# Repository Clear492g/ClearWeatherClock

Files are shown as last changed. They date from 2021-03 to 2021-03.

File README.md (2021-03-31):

# [ClearWeatherClock]拟辉光管气象钟开源文档

## 效果图

效果图

## 简述

该项目基于立创开源拟辉光钟项目和零知实验室开源ESP8266气象站项目。

只作为Demo版本发布 更多特效、功能欢迎各位有能力的朋友继续二次开发

- 核心主控为NodeMCU/ESP8266开发板 底座体积足够就没有额外画PCB（1688的NodeMCU七八块钱）
- WIFI联网 EEPROM断电保存 串口通讯
- 驱动120颗WS2812灯珠实现亚克力数字时钟展示 亮度可调 颜色可独立更改 断电记忆
- 加入旋钮通过ADC控制整体灯光亮度 预留开关位置
- 驱动0.96寸OLED屏幕作为副屏 显示更多的内容
- 驱动DHT11/22获取室内温度和湿度 OLED左右下脚
- 基于Qt编写上位机程序 功能见图

上位机

***

## 硬件准备

> 链接什么的我找找  尽量找到可以准确的我测试没问题的 先暂时这么看着

1. ESP8266开发板 *1
2. 0.96 OLED 1306屏幕  *1
3. DHT11/22 温湿度传感器 *1
4. 旋钮电位器 *1
5. 带WS2812的灯板PCB *3
6. 亚克力数字0-9 *6
7. 亚克力外壳、束光板等套装 *1
8. M3螺柱 M3螺钉若干
9. 杜邦线、电烙铁等各种工具

> 这个表可能是对的  抽空我会再整理下的

| 名称 | 数量 | 单价 | 每套总价 | 库存余量 | 库存余套 |
| --- | ---- | ---- | --- | --- | --- |
| 灯板PCB+元件+SMT（WS2812  0.1u电容（0805贴片）） | 3 | 22 | 66 | 26坏1 | 8 |
| XH4A连接座/排针  + 排线 | 6 | / | 3 | 0 | 0 |
| WH138 10K+铝电位器旋钮（15*17） | 1 | 2 | 2 | 12 | 12 |
| 小正方体1CM 用于固定底座 | 10 | 0.2  | 2 | 60 | 6 |
| 亚克力套装（数字加束光+底座） | 1 | | | 0 | 0 |
| OLED 0.96 SSD 1306（IIC） | 1 | 10 | 10 | 9 | 9 |
| ESP8266（NodeMCU/ESP12E） | 1 | 13 | 13 | 7 | 7 |
| 螺丝铜柱等（M3*55铜柱*12 M3*12螺丝*26 M3螺母*24） | 1 | 11 | 11 | 10 | 10 |
| 脚垫 12mm*5mm | 4 | 0.15 | 1 | 64 | 16 |
| 防尘网 | 1 | 1 | 1 | 24 | 24 |
| DHT11（3线） | 1 | 4 | 4 | 0 | 0 |

## 附件结构

/QtPro：上位机源代码

/ESPArduino: 单片机的源代码

/QtBin：上位机打包好的程序

/ESPBin：单片机打包好的固件及工具

## 使用说明

1. 完成硬件组装 确保硬件正确连接
2. 向单片机烧录固件 
3. Windows平台安装上位机程序    **同时安装串口驱动CH340/CP2102**
4. 上位机通过串口连接气象钟 Load载入当前参数 按需修改WIFI/天气API等参数
5. 调节亮度/颜色等

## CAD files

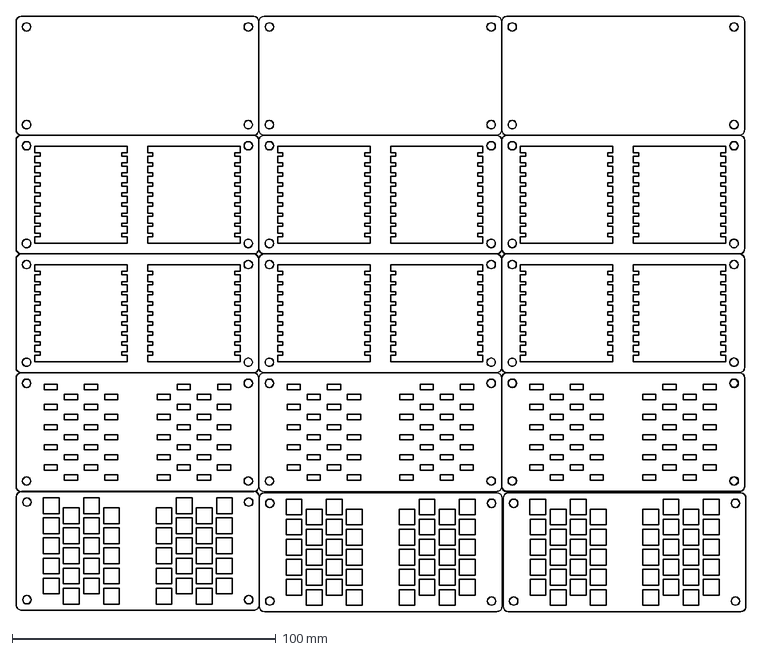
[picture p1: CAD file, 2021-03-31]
图纸/束光板等其他结构_黑色不透明_2mm.dxf
276.5 x 225.5 mm

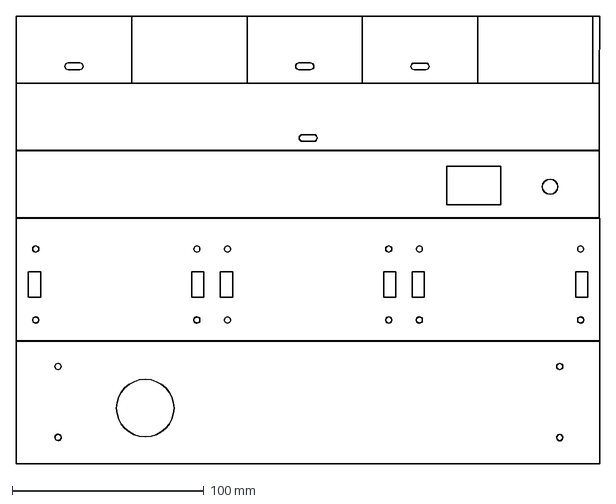
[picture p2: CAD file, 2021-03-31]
图纸/底座盒子_黑色不透明_2mm.dxf
304.0 x 233.4 mm

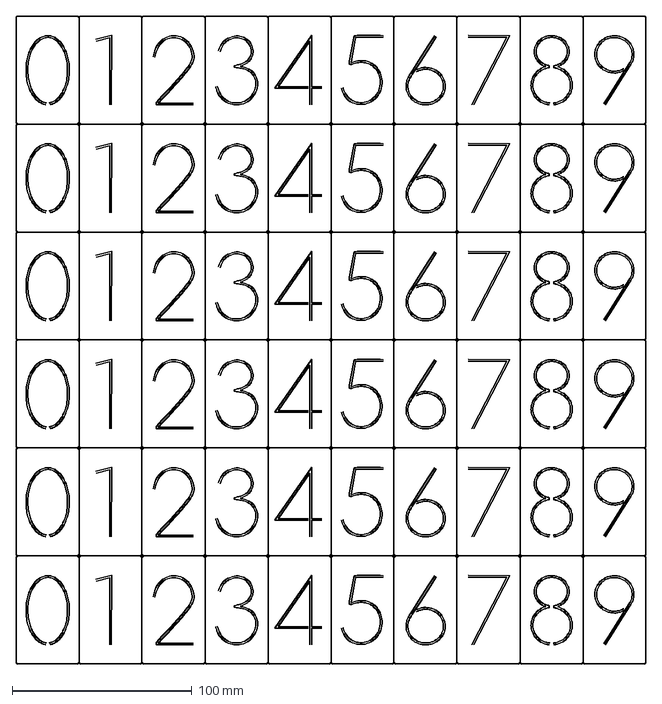
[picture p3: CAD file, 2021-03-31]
图纸/亚克力数字板_无色透明2.5mm.dxf
350.0 x 360.0 mm

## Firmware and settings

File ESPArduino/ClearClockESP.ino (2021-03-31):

#include "ClearDefine.h"

void setup() {
  Serial.begin(115200);
  Serial.println();

  WS2812.Begin();  //ws2812
  WS2812.ClearTo(black);
  WS2812.Show();

  display.init();  // OLED
  display.clear();
  display.display();
  display.setFont(ArialMT_Plain_10);
  display.setTextAlignment(TEXT_ALIGN_CENTER);
  display.setContrast(255);//设置对比度

  //sensors.begin(); //初始化总线18b20
  //sensors.setWaitForConversion(false); //设置为非阻塞模式

  loadConfig();
  if (config.OPEN_WEATHER_MAP_APP_ID == "ClearReset") //重置模式
  {
    strcpy(config.WIFI_SSID, "Clear9700");
    strcpy(config.WIFI_PWD, "918888888");
    strcpy(config.OPEN_WEATHER_MAP_APP_ID, "3213ac05f30cc2f7d8d8da6d2b03f2e8");
    strcpy(config.OPEN_WEATHER_MAP_LOCATION_ID, "1816670");
    for (int i = 0 ; i < 18 ; i++)
    {
      config.EEPROM_Colors[i] = 255;
    }
    config.WS2812Brightnesslimit = 255;
    saveConfig();
  }

  for (int i = 0; i < 6 ; i++)
  {
    ClearRGB[i][0] = config.EEPROM_Colors[i * 3 + 0];
    ClearRGB[i][1] = config.EEPROM_Colors[i * 3 + 1];
    ClearRGB[i][2] = config.EEPROM_Colors[i * 3 + 2];
  }

  WifiConnect();

  ui.setTargetFPS(30);//为了妥协WS2812的性能  可适当降低
  ui.setActiveSymbol(activeSymbole);
  ui.setInactiveSymbol(inactiveSymbole);
  ui.setIndicatorPosition(BOTTOM);// TOP, LEFT, BOTTOM, RIGHT
  ui.setIndicatorDirection(LEFT_RIGHT);// 定义第一帧在栏中的位置
  ui.setFrameAnimation(SLIDE_LEFT);//动画效果/ SLIDE_LEFT, SLIDE_RIGHT, SLIDE_TOP, SLIDE_DOWN
  ui.setFrames(frames, 3);//页面数量
  ui.setOverlays(overlays, 1);//numberOfOverlays
  ui.init();

  OLED_updateData(&display);
}

void loop() {

  if (millis() - timeSinceLastWUpdate > (1000L * UPDATE_INTERVAL_SECS))
    //如果距离上次更新时间超过设定  millis()函数用于返回的Arduino板开始运行当前程序时的毫秒数。这个数字在大约50天后溢出，即回到零。
  {
    OLED_setReadyForWeatherUpdate();//准备更新标志启用
    timeSinceLastWUpdate = millis();
  }

  if (readyForWeatherUpdate && ui.getUiState()->frameState == FIXED)
  {
    OLED_updateData(&display);
  }

  int remainingTimeBudget = ui.update();//剩余时间预算

  if (remainingTimeBudget > 0)
  {
    SerialSlot();

    //Update18b20();

    now = time(nullptr);//更新WS2812的时间
    struct tm* timeInfo;
    timeInfo = localtime(&now);
    char buff[14];
    sprintf_P(buff, PSTR("%02d:%02d"), timeInfo->tm_hour, timeInfo->tm_min);
    WS2812LED(timeInfo->tm_hour, timeInfo->tm_min, timeInfo->tm_sec);



    //    if (     (    (millis() - timeSinceLastWUpdate - (1000L * UPDATE_INTERVAL_SECS))  > (0 - (1000L * 30))    ) && (    (millis() - timeSinceLastWUpdate - (1000L * UPDATE_INTERVAL_SECS))  > ((1000L * 30))    ) )
    //    {
    //      WifiConnect();
    //    }
    //
    //    else
    //    {
    //      if ((WiFi.status() == WL_CONNECTED) && (String(timeInfo->tm_year + 1900) == "1970")   )
    //      {
    //        WiFi.stop;
    //      }
    //    }

    if ((timeInfo->tm_sec % 10) != 9)
    {
      int sensorValue = analogRead(A0);
      float  WS2812Brightness = sensorValue / 1023.0;
      WS2812.SetBrightness((int)((float)(config.WS2812Brightnesslimit) * (1.0 - WS2812Brightness)));
      //WS2812.SetBrightness((int)((float)(config.WS2812Brightnesslimit) * (WS2812Brightness)));
    }




  }





}

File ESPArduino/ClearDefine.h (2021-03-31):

#include <ESP8266WiFi.h>
#include <ESPHTTPClient.h>
#include <JsonListener.h>
#include <time.h>                       // time() ctime()函数
#include <sys/time.h>                   // struct timeval//time结构体
#include "ArduinoJson.h"
//#include <coredecls.h>                  // settimeofday_cb()
#include "SSD1306Wire.h"
#include "OLEDDisplayUi.h"
#include "Wire.h"
#include "OpenWeatherMapCurrent.h"
#include "OpenWeatherMapForecast.h"
#include "WeatherStationFonts.h"
#include "WeatherStationImages.h"
#include <EEPROM.h>
//#include <DallasTemperature.h>//18B20
#include <NeoPixelBus.h>//WS2812
#include <NeoPixelBrightnessBus.h>//WS2812
#include <SimpleDHT.h>

//函数申明
void OLED_drawProgress(OLEDDisplay *display, int percentage, String label);//画进度条 屏幕对象 百分比 文字
void OLED_updateData(OLEDDisplay *display);  //绘制更新天气时间画面进度 屏幕对象
void OLED_drawDateTime(OLEDDisplay *display, OLEDDisplayUiState* state, int16_t x, int16_t y);//第一页把日期和时间绘制上去
void OLED_drawCurrentWeather(OLEDDisplay *display, OLEDDisplayUiState* state, int16_t x, int16_t y);//第二页绘制当前天气
void OLED_drawForecast(OLEDDisplay *display, OLEDDisplayUiState* state, int16_t x, int16_t y);//第三页绘制所有天气预报
void OLED_drawForecastDetails(OLEDDisplay *display, int x, int y, int dayIndex);//第三页绘制某天的天气状况
void OLED_drawHeaderOverlay(OLEDDisplay *display, OLEDDisplayUiState* state);//绘制底部的时间和气温
void OLED_setReadyForWeatherUpdate();

void WifiConnect();//连接wifi
void saveConfig();//EEPROM Config信息保存
void loadConfig();//EEPROM Config信息加载
void SerialSlot();//串口接收处理
//void Update18b20();//达到某值时更新18B20数据
void WS2812LED(int hours, int minutes, int seconds);//WS2812彩色LED底层
int  WS2812GetLEDNoByNum(int i, int num) ;//获取LED序号  i为1-6    num为1-10


//Config变量
struct config_type
{
  char WIFI_SSID[32];
  char WIFI_PWD[64];
  char OPEN_WEATHER_MAP_APP_ID[256];
  char OPEN_WEATHER_MAP_LOCATION_ID[32] ;
  int EEPROM_Colors[18];
  int WS2812Brightnesslimit;
};

//全局变量
config_type config;//系统配置文件 EEPROM

int UPDATE_INTERVAL_SECS = 120 * 60; // 每120/60=2小时更新一次
time_t now;//time_t类型的变量  now
const int I2C_DISPLAY_ADDRESS = 0x3c;
const int SDC_PIN = D2;
const int SDA_PIN = D3;
String OPEN_WEATHER_MAP_LANGUAGE = "en";//"zh_cn"
const uint8_t MAX_FORECASTS = 3;//预报的天数  包括当天
const boolean IS_METRIC = true;//应该是采用摄氏度
const String WDAY_NAMES[] = {"SUN", "MON", "TUE", "WED", "THU", "FRI", "SAT"};
const String MONTH_NAMES[] = {"JAN", "FEB", "MAR", "APR", "MAY", "JUN", "JUL", "AUG", "SEP", "OCT", "NOV", "DEC"};
SSD1306Wire     display(I2C_DISPLAY_ADDRESS, SDA_PIN, SDC_PIN);
OLEDDisplayUi   ui( &display );
OpenWeatherMapCurrentData currentWeather;
OpenWeatherMapCurrent currentWeatherClient;
OpenWeatherMapForecastData forecasts[MAX_FORECASTS];
OpenWeatherMapForecast forecastClient;
bool readyForWeatherUpdate = false;
long long timeSinceLastWUpdate = 0;
FrameCallback frames[] = { OLED_drawDateTime, OLED_drawCurrentWeather, OLED_drawForecast };
OverlayCallback overlays[] = { OLED_drawHeaderOverlay };


String SerialRecData = "";
DynamicJsonDocument  JosnSerialRecData(200);


//unsigned long previousMillis = 0; //毫秒时间记录  18B20
//const long interval = 3000;       //时间间隔 18B20
//float Temp_18b20 = 0;
//OneWire oneWire(D4);       ////1-wire数据总线连接在IO4  18B20
//DallasTemperature sensors(&oneWire); //声明   18B20

const uint16_t PixelCount = 120; 
const uint8_t PixelPin = 2;
//NeoPixelBus<NeoGrbFeature, NeoEsp8266Dma400KbpsMethod> strip(PixelCount, PixelPin);  //D9/GPIO3
//NeoPixelBus<NeoRgbFeature, NeoEsp8266Uart0Ws2812xMethod> strip(PixelCount, PixelPin);//GPIO1/TXDO/TX
NeoPixelBrightnessBus<NeoRgbFeature, NeoEsp8266Uart1Ws2812xMethod> WS2812(PixelCount, PixelPin);//GPIO2/TXD1/D4
RgbColor white(255,255,255);
RgbColor black(0);
int ClearRGB[6][3]={{142,68,173},{52,152,219 },{26,188,156 },
                    {241,196,15},{211,84,0 },{247,249,249 }};
int WS2812Second=0;//最低位置更新再刷  不更新则不刷  节省性能开销

SimpleDHT11 dht11(D1);
byte DHT11_temperature = 0;
byte DHT11_humidity = 0;

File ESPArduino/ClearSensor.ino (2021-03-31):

//void Update18b20() {
//  if (millis() - previousMillis >= interval) //如果和前次时间大于等于时间间隔
//  {
//    previousMillis = millis(); //更新时间记录
//
//    float tempC = sensors.getTempCByIndex(0); //获取索引号0的传感器摄氏温度数据
//    if (tempC != DEVICE_DISCONNECTED_C)       //如果获取到的温度正常
//    {
//      Temp_18b20 = tempC;
//    }
//    sensors.requestTemperatures(); //发起新的温度转换
//  }
//}

void WS2812LED(int hours, int minutes, int seconds)
{
  if (seconds != WS2812Second)
  //if (1)
  {
    int NumberToShow[6 ] = {hours / 10, hours % 10, minutes / 10, minutes % 10, seconds / 10, seconds % 10};

    
/***************  动画尝试  ************** */
  if(NumberToShow[5]==0)
  {
     WS2812.SetPixelColor(WS2812GetLEDNoByNum(6, 9 ), RgbColor(0));
     WS2812.SetPixelColor(WS2812GetLEDNoByNum(6, 8 ), RgbColor(ClearRGB[5][1], ClearRGB[5][0], ClearRGB[5][2])); //12:34:56中的1  
     WS2812.Show();delay(50);
     WS2812.SetPixelColor(WS2812GetLEDNoByNum(6, 8 ), RgbColor(0));
     WS2812.SetPixelColor(WS2812GetLEDNoByNum(6, 7 ), RgbColor(ClearRGB[5][1], ClearRGB[5][0], ClearRGB[5][2])); //12:34:56中的1  
     WS2812.Show();delay(50);
     WS2812.SetPixelColor(WS2812GetLEDNoByNum(6, 7 ), RgbColor(0));
     WS2812.SetPixelColor(WS2812GetLEDNoByNum(6, 6 ), RgbColor(ClearRGB[5][1], ClearRGB[5][0], ClearRGB[5][2])); //12:34:56中的1  
     WS2812.Show();delay(50);
     WS2812.SetPixelColor(WS2812GetLEDNoByNum(6, 6 ), RgbColor(0));
     WS2812.SetPixelColor(WS2812GetLEDNoByNum(6, 5 ), RgbColor(ClearRGB[5][1], ClearRGB[5][0], ClearRGB[5][2])); //12:34:56中的1  
     WS2812.Show();delay(50);
     WS2812.SetPixelColor(WS2812GetLEDNoByNum(6, 5 ), RgbColor(0));
     WS2812.SetPixelColor(WS2812GetLEDNoByNum(6, 4 ), RgbColor(ClearRGB[5][1], ClearRGB[5][0], ClearRGB[5][2])); //12:34:56中的1  
     WS2812.Show();delay(50);
     WS2812.SetPixelColor(WS2812GetLEDNoByNum(6, 4 ), RgbColor(0));
     WS2812.SetPixelColor(WS2812GetLEDNoByNum(6, 3 ), RgbColor(ClearRGB[5][1], ClearRGB[5][0], ClearRGB[5][2])); //12:34:56中的1  
     WS2812.Show();delay(50);
     WS2812.SetPixelColor(WS2812GetLEDNoByNum(6, 3 ), RgbColor(0));
     WS2812.SetPixelColor(WS2812GetLEDNoByNum(6, 2 ), RgbColor(ClearRGB[5][1], ClearRGB[5][0], ClearRGB[5][2])); //12:34:56中的1  
     WS2812.Show();delay(50);
     WS2812.SetPixelColor(WS2812GetLEDNoByNum(6, 2 ), RgbColor(0));
     WS2812.SetPixelColor(WS2812GetLEDNoByNum(6, 1 ), RgbColor(ClearRGB[5][1], ClearRGB[5][0], ClearRGB[5][2])); //12:34:56中的1  
     WS2812.Show();delay(50);
    }
    


    WS2812.ClearTo(black);

    for (int i = 1; i <= 6; i++)
    {
      int LED_NoNum = WS2812GetLEDNoByNum(i, NumberToShow[i - 1] );
      WS2812.SetPixelColor(LED_NoNum, RgbColor(ClearRGB[i - 1][1], ClearRGB[i - 1][0], ClearRGB[i - 1][2])); //12:34:56中的1
      WS2812.SetPixelColor(LED_NoNum + 10, RgbColor(ClearRGB[i - 1][1], ClearRGB[i - 1][0], ClearRGB[i - 1][2])); //12:34:56中的1
    }
    WS2812.Show();
    WS2812Second = seconds;

    if (NumberToShow[5] % 5 == 2)
    {
      int err = SimpleDHTErrSuccess;
      if ((err = dht11.read(&DHT11_temperature, &DHT11_humidity, NULL)) != SimpleDHTErrSuccess)
      {
        Serial.print("Read DHT11 failed, err="); Serial.println(err);
       }       
    }


  }

}

int WS2812GetLEDNoByNum(int i, int num)//获取LED序号  i为1-6    num为1-10
{
  if ((i + 1) % 2 == 0)
  {
    switch (num)
    {
      case 0 : return (i - 1) * 20 + 5;
      case 1 : return (i - 1) * 20 + 4;
      case 2 : return (i - 1) * 20 + 6;
      case 3 : return (i - 1) * 20 + 3;
      case 4 : return (i - 1) * 20 + 7;
      case 5 : return (i - 1) * 20 + 2;
      case 6 : return (i - 1) * 20 + 8;
      case 7 : return (i - 1) * 20 + 1;
      case 8 : return (i - 1) * 20 + 9;
      case 9 : return (i - 1) * 20 + 0;
    }
  }
  else
  {
    switch (num)
    {
      case 0 : return (i - 1) * 20 + 4;
      case 1 : return (i - 1) * 20 + 5;
      case 2 : return (i - 1) * 20 + 3;
      case 3 : return (i - 1) * 20 + 6;
      case 4 : return (i - 1) * 20 + 2;
      case 5 : return (i - 1) * 20 + 7;
      case 6 : return (i - 1) * 20 + 1;
      case 7 : return (i - 1) * 20 + 8;
      case 8 : return (i - 1) * 20 + 0;
      case 9 : return (i - 1) * 20 + 9;
    }
  }

}
